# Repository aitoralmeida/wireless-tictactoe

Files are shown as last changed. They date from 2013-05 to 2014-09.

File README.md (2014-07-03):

wireless-tictactoe
==================

Wireless Tic-Tac-Toe for the THOFU project

Tested with Arduino Mega 2560

Uses https://github.com/joruiz/shiftduino to control the shift registers

 * TicTacToe folder contains the Arduino code
 * PCBSchemas folder contains the Eagle PCB schemas (Square folder contais the schema for each one of the 9 squares)

   This work has been supported by project grant CEN-20101019 (THOFU), funded
by the Spanish Centro para el Desarrollo Tecnol ogico Industrial (CDTI) and
supported by the Spanish Ministerio de Economía y Competitividad.

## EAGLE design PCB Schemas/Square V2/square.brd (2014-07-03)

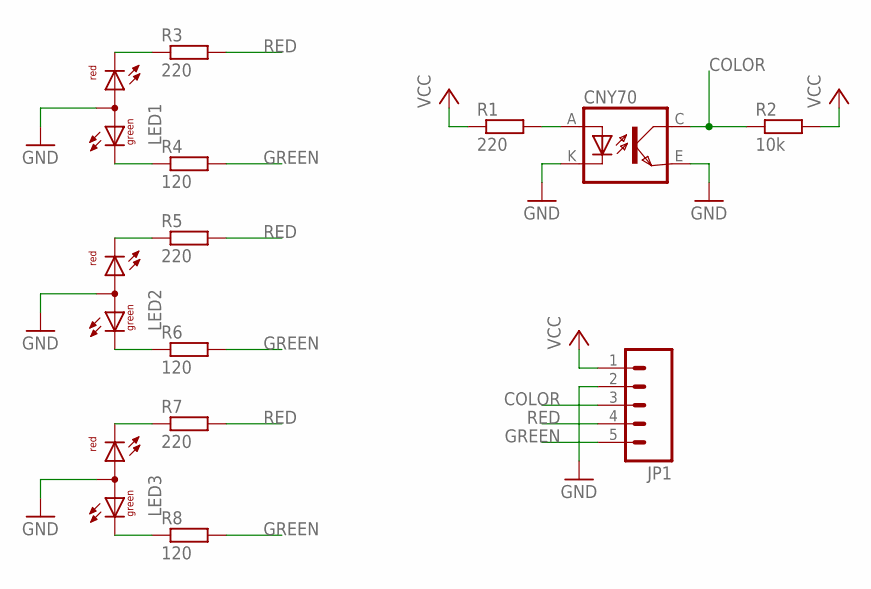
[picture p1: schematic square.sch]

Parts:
CNY70: CNY70; 4
JP1: M05PTH; 1X05
LED1, LED2, LED3: L-115WEGW-CA; DUOLED-A-3MM
R1, R3, R5, R7: 220; 0204/7
R2: 10k; 0204/7
R4, R6, R8: 120; 0204/7

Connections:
COLOR: CNY70.C (COL), JP1.3, R2.1
GND: CNY70.E (EMI), CNY70.K (C), JP1.2, LED1.2 (A), LED2.2 (A), LED3.2 (A)
GREEN: JP1.5, R4.2, R6.2, R8.2
unnamed: CNY70.A, R1.2
unnamed: LED1.3 (CR), R3.1
unnamed: LED2.3 (CR), R5.1
unnamed: LED3.3 (CR), R7.1
unnamed: LED2.1 (CG), R6.1
unnamed: LED1.1 (CG), R4.1
unnamed: LED3.1 (CG), R8.1
RED: JP1.4, R3.2, R5.2, R7.2
VCC: JP1.1, R1.1, R2.2

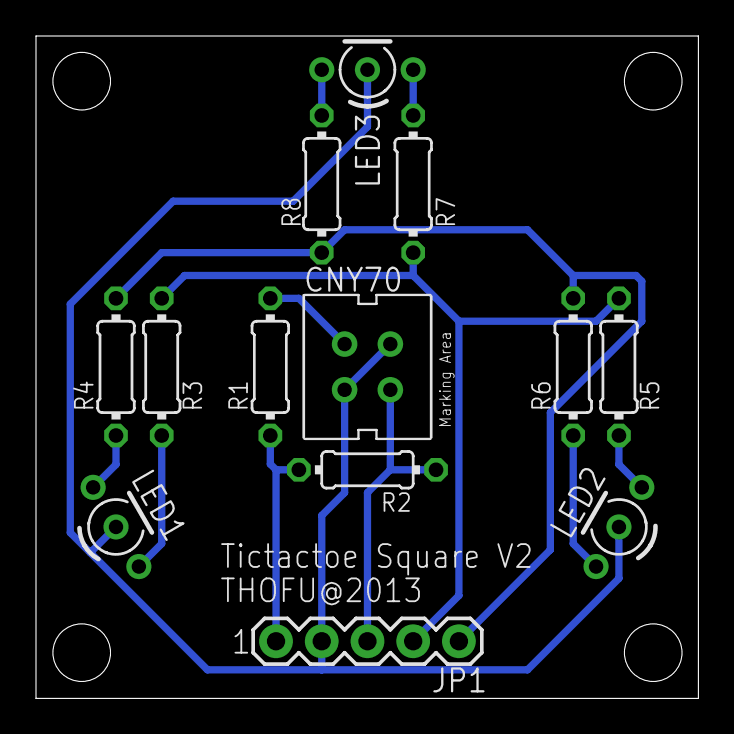
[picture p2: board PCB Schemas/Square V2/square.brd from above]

Board: 2 copper layers, 36.8 x 36.8 mm, 13 parts (0 on the bottom side), 12 nets.

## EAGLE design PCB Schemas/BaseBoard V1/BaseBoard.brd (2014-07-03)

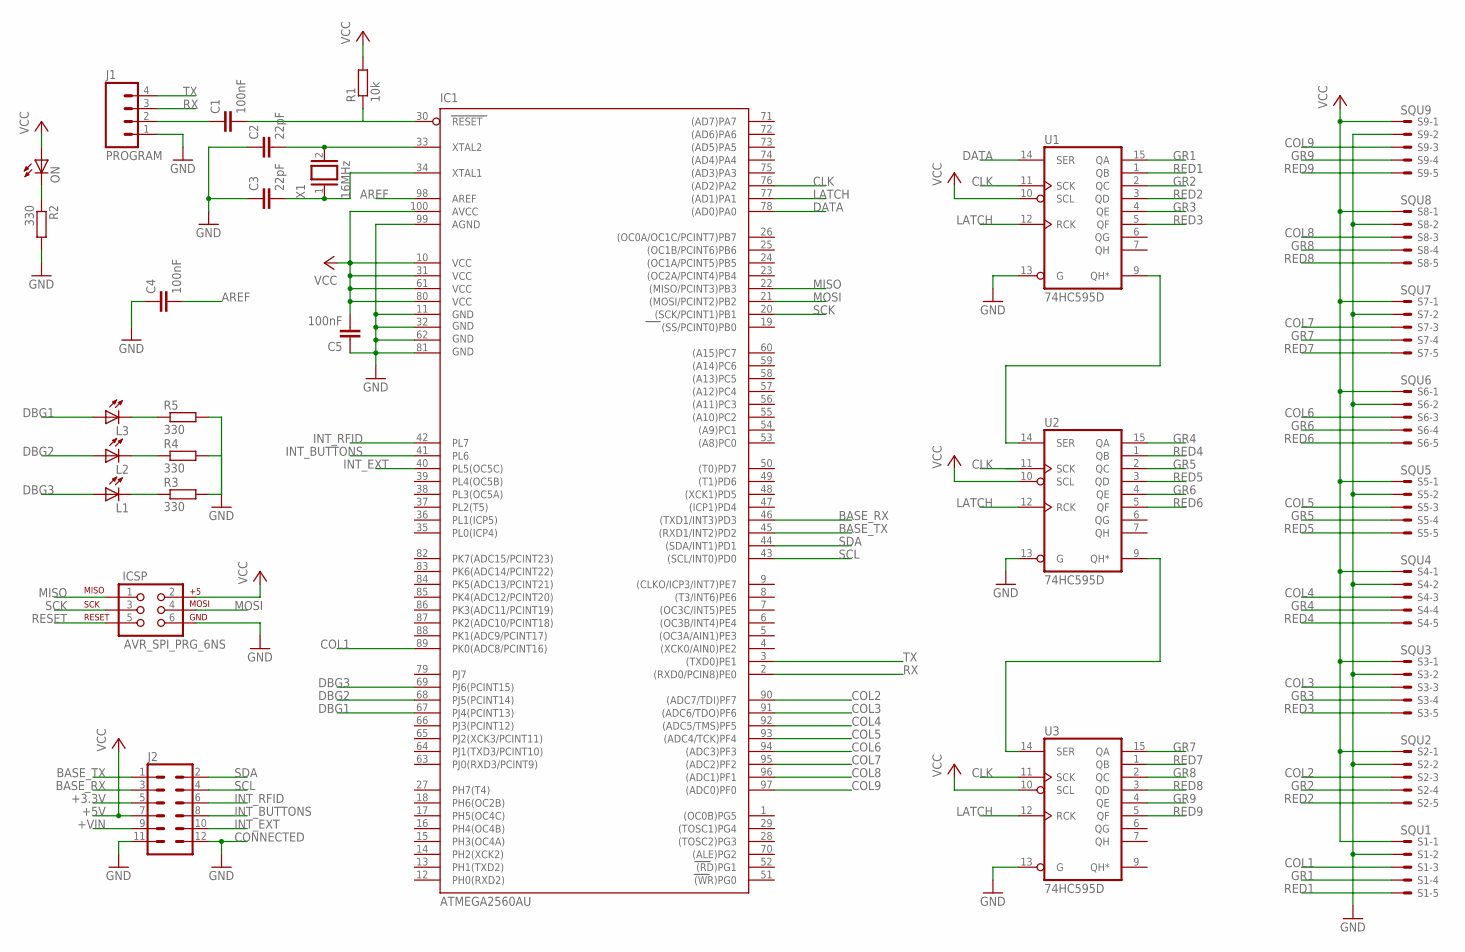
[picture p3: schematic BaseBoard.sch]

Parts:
C1, C4, C5: 100nF; C0805
C2, C3: 22pF; C0805
IC1: ATMEGA2560AU; TQFP100
ICSP: AVR_SPI_PRG_6NS; 2X3-NS
J1: PROGRAM; 1X04
J2: CON06X2-2MM; CON06X2_2MM
L1, L2, L3: LEDCHIP-LED0805; CHIP-LED0805
ON: LEDCHIP-LED0805; CHIP-LED0805
R1: 10k; R0805
R2, R3, R4, R5: 330; R0805
S1: SQU1; 53261-05
S2: SQU2; 53261-05
S3: SQU3; 53261-05
S4: SQU4; 53261-05
S5: SQU5; 53261-05
S6: SQU6; 53261-05
S7: SQU7; 53261-05
S8: SQU8; 53261-05
S9: SQU9; 53261-05
U1, U2, U3: 74HC595D; SO16
X1: 16MHz; QS

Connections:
+3.3V: J2.5
+VIN: J2.9
AREF: C4.2, IC1.98 (AREF)
BASE_RX: IC1.46 ((TXD1/INT3)PD3), J2.3
BASE_TX: IC1.45 ((RXD1/INT2)PD2), J2.1
CLK: IC1.76 ((AD2)PA2), U1.11 (SCK), U2.11 (SCK), U3.11 (SCK)
COL1: IC1.89 (PK0(ADC8/PCINT16)), S1.3
COL2: IC1.90 ((ADC7/TDI)PF7), S2.3
COL3: IC1.91 ((ADC6/TDO)PF6), S3.3
COL4: IC1.92 ((ADC5/TMS)PF5), S4.3
COL5: IC1.93 ((ADC4/TCK)PF4), S5.3
COL6: IC1.94 ((ADC3)PF3), S6.3
COL7: IC1.95 ((ADC2)PF2), S7.3
COL8: IC1.96 ((ADC1)PF1), S8.3
COL9: IC1.97 ((ADC0)PF0), S9.3
DATA: IC1.78 ((AD0)PA0), U1.14 (SER)
DBG1: IC1.67 (PJ4(PCINT13)), L3.A
DBG2: IC1.68 (PJ5(PCINT14)), L2.A
DBG3: IC1.69 (PJ6(PCINT15)), L1.A
GND: C2.1, C3.1, C4.1, C5.1, IC1.11 (GND), IC1.32 (GND1), IC1.62 (GND2), IC1.81 (GND3), IC1.99 (AGND), ICSP.6, J1.1, J2.11, J2.12, R2.2, R3.2, R4.2, R5.2, S1.2, S2.2, S3.2, S4.2, S5.2, S6.2, S7.2, S8.2, S9.2, U1.8 (GND), U1.13 (G), U2.8 (GND), U2.13 (G), U3.8 (GND), U3.13 (G)
GR1: S1.4, U1.15 (QA)
GR2: S2.4, U1.2 (QC)
GR3: S3.4, U1.4 (QE)
GR4: S4.4, U2.15 (QA)
GR5: S5.4, U2.2 (QC)
GR6: S6.4, U2.4 (QE)
GR7: S7.4, U3.15 (QA)
GR8: S8.4, U3.2 (QC)
GR9: S9.4, U3.4 (QE)
INT_BUTTONS: IC1.41 (PL6), J2.8
INT_EXT: IC1.40 (PL5(OC5C)), J2.10
INT_RFID: IC1.42 (PL7), J2.6
LATCH: IC1.77 ((AD1)PA1), U1.12 (RCK), U2.12 (RCK), U3.12 (RCK)
MISO: IC1.22 ((MISO/PCINT3)PB3), ICSP.1
MOSI: IC1.21 ((MOSI/PCINT2)PB2), ICSP.4
unnamed: C2.2, IC1.33 (XTAL2), X1.2
unnamed: C3.2, IC1.34 (XTAL1), X1.1
unnamed: L2.C, R4.1
unnamed: L1.C, R3.1
unnamed: C1.1, J1.2
unnamed: U1.9 (QH*), U2.14 (SER)
unnamed: U2.9 (QH*), U3.14 (SER)
unnamed: ON.C, R2.1
unnamed: L3.C, R5.1
RED1: S1.5, U1.1 (QB)
RED2: S2.5, U1.3 (QD)
RED3: S3.5, U1.5 (QF)
RED4: S4.5, U2.1 (QB)
RED5: S5.5, U2.3 (QD)
RED6: S6.5, U2.5 (QF)
RED7: S7.5, U3.1 (QB)
RED8: S8.5, U3.3 (QD)
RED9: S9.5, U3.5 (QF)
RESET: C1.2, IC1.30 (RESET), ICSP.5, R1.1
RX: IC1.2 ((RXD0/PCIN8)PE0), J1.3
SCK: IC1.20 ((SCK/PCINT1)PB1), ICSP.3
SCL: IC1.43 ((SCL/INT0)PD0), J2.4
SDA: IC1.44 ((SDA/INT1)PD1), J2.2
TX: IC1.3 ((TXD0)PE1), J1.4
VCC: C5.2, IC1.10 (VCC), IC1.31 (VCC1), IC1.61 (VCC2), IC1.80 (VCC3), IC1.100 (AVCC), ICSP.2, J2.7, ON.A, R1.2, S1.1, S2.1, S3.1, S4.1, S5.1, S6.1, S7.1, S8.1, S9.1, U1.10 (SCL), U1.16 (VCC), U2.10 (SCL), U2.16 (VCC), U3.10 (SCL), U3.16 (VCC)

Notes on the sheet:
CONNECTED
+5V

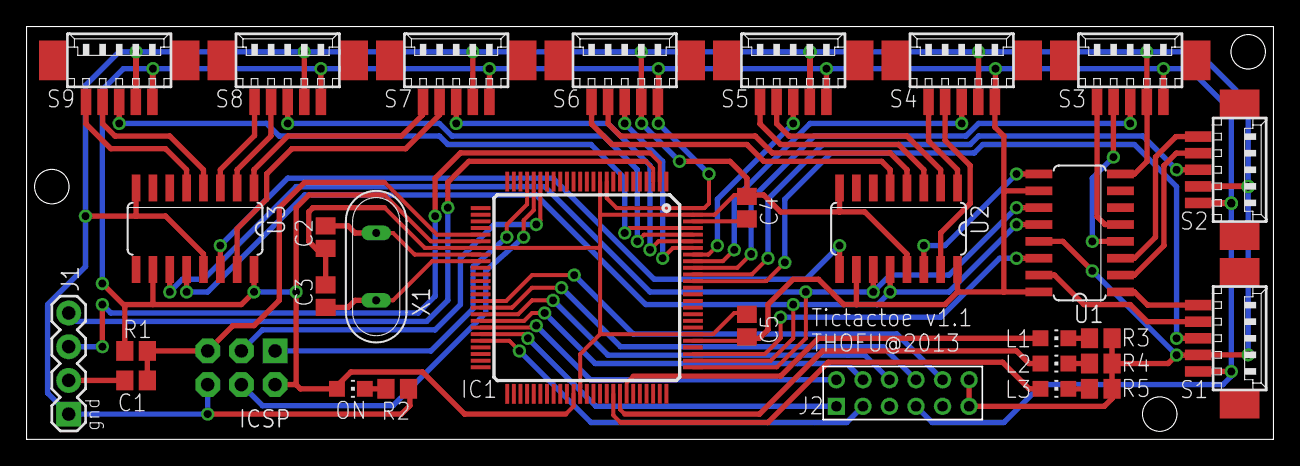
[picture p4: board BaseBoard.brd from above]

Board: 2 copper layers, 94.0 x 31.1 mm, 31 parts (0 on the bottom side), 58 nets.

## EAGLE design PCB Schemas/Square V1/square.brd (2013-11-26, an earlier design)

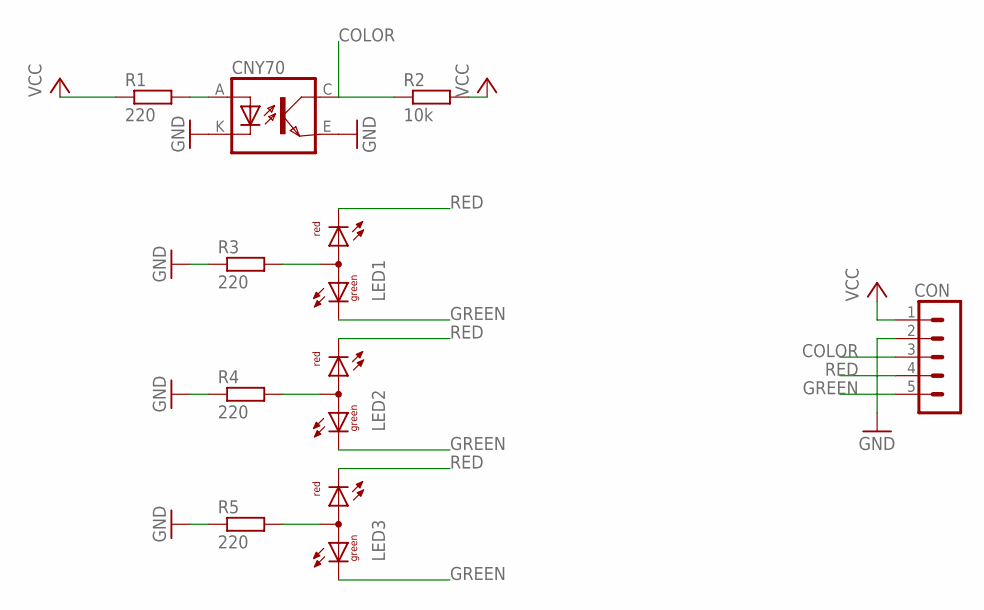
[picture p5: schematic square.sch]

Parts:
CNY70: CNY70; 4
CON: CON05; CON05_2.54MM
LED1, LED2, LED3: L-115WEGW-CA; DUOLED-A-3MM
R1, R3, R4, R5: 220; 0204/7
R2: 10k; 0204/7

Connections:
COLOR: CNY70.C (COL), CON.3, R2.1
GND: CNY70.E (EMI), CNY70.K (C), CON.2, R3.1, R4.1, R5.1
GREEN: CON.5, LED1.1 (CG), LED2.1 (CG), LED3.1 (CG)
unnamed: LED1.2 (A), R3.2
unnamed: CNY70.A, R1.2
unnamed: LED2.2 (A), R4.2
unnamed: LED3.2 (A), R5.2
RED: CON.4, LED1.3 (CR), LED2.3 (CR), LED3.3 (CR)
VCC: CON.1, R1.1, R2.2

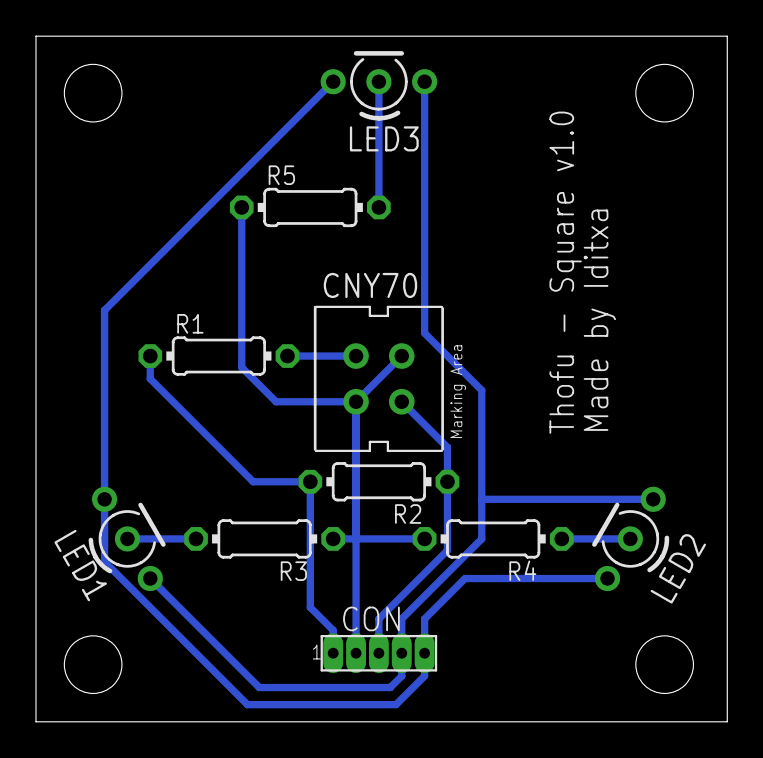
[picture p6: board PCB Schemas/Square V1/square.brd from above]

Board: 2 copper layers, 38.4 x 38.1 mm, 10 parts (0 on the bottom side), 9 nets.

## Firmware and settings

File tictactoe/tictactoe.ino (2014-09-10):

#include <Shiftduino.h>
#include "Square.h"

#include <Wire.h>
#include <GraphicDisplay.h>
#include <SM125.h> //RFID
#include <SoundPlayer.h>

//Game ID
#define GAME_ID 0x01 //tictactoe
//Board ID
#define BOARD_ID 0x07 //TODO: Change it for each board
#define PLAYER__ID "7000"

// Hardware addresses
#define DISPLAY_ADDRESS  0x51
#define BUTTONS_CHANGE   43
#define SM125_ADDRESS 0x46
// Sound files
#define WELCOME 0x1 //Welcome screen
#define YOU_WIN 0x2 //The Player wins :-)
#define YOU_LOSE 0x3 //The Rival wins :-(
#define VICTORY_LOOP 0x4 //Victory loop!!!
#define NO_NO 0x7 //Illegal move
// Image addresses
#define GAME_OVER 0x0049
#define WINNER 0x00DB
#define TICTACTOE 0x0092
#define DOWN_OFFSET 11 // How many pixels we are leaving for the status bar

// Communication msgs
String MSG_REGISTER = "REGISTER"; // id
String MSG_FIND_GAME = "FIND_GAME"; // id
String MSG_DO_MOVE =  "DO_MOVE"; // id movement(0..8)
String MSG_GET_MOVE = "GET_MOVE"; // id
String MSG_GAMEID = "GAMEID"; //id
String MSG_OK = "OK";
String END_CHAR = "\r"; 
String SEP_CHAR_COMMANDS = " ";
String SEP_CHAR_PARAMETERS = ",";
// Server commands
String CMD_WAITING_PLAYERS = "WAITING_FOR_PLAYERS";
String CMD_RIVAL = "RIVAL"; // rival_id turn(0/1)
String CMD_NOT_REGISTERED = "NOT_REGISTERED";
String CMD_WAIT_FOR_MOVE = "WAIT_FOR_MOVE";
String CMD_WAIT_FOR_RIVAL = "WAIT_FOR_RIVAL";
String CMD_WAIT_FOR_TURN = "WAIT_FOR_TURN";
String CMD_RIVAL_MOVE = "RIVAL_MOVE"; // # rival_id move
String CMD_ACK = "ACK"; // rival_id move
String CMD_START_PLAYING = "PLAY";
String CMD_GET_GAMEID = "GET_GAMEID";



// Baseboard screen
GraphicDisplay display;
// Baseboard RFID reader
SM125 sm125;
// Baseboard sound player
SoundPlayer soundPlayer;

// Configuration for the shift registers
int numShifts = 3;
int datapin = 22;
int clockpin = 24;
int latchpin = 23;

Shiftduino _sd(datapin, clockpin, latchpin, numShifts);

// Unique board ID (TODO: right now is set manually for testing purposes)
String player_id = PLAYER__ID;
// Rival board id
String rival_id = "0";
// Who starts playing: 0 the player, 1 the rival.
String start_turn = "2";

// Current turn
int turn = 0;

// Each of the squares of the tictactoe
Square * squares[9];

//int gameStatus = 0; //0 = ongoing game, 1 = you win, 2 = opponent wins
//int currentTurn = 0; //0 you, 1 opponent

// square status
int redStatus [] = {
  0,0,0,0,0,0,0,0,0};
int greenStatus [] = {
  0,0,0,0,0,0,0,0,0};
int previousGreenStatus [] = {
  0,0,0,0,0,0,0,0,0};

// conditions for victory
int winConditions [][9] = {
  {
    1,1,1,0,0,0,0,0,0  }
  ,
  {
    0,0,0,1,1,1,0,0,0  }
  ,
  {
    0,0,0,0,0,0,1,1,1  }
  ,
  {
    1,0,0,1,0,0,1,0,0  }
  ,
  {
    0,1,0,0,1,0,0,1,0  }
  ,
  {
    0,0,1,0,0,1,0,0,1  }
  ,
  {
    1,0,0,0,1,0,0,0,1  }
  ,
  {
    0,0,1,0,1,0,1,0,0  }
};

boolean redVictory = false;
boolean greenVictory = false;

// hardware initialization
void setup() {
  // 0 - Initialize serial comms  
  Serial.begin(9600); // USB comm for debugging purposes
  Serial1.begin(9600); // Comm with the base board
  
  Serial.println("*****************");
  Serial.println("***** Setup *****");
  Serial.println("*****************");
  
  // 1 - Initialize the tictactoe board
  Serial.println("Initializing tictactoe squares...");
  
  for (int i = 0; i < 9; i++){
    squares[i] = new Square(8 - i, i + 1, &_sd);
  }
  Serial.println("-Calibrating sensors.");
  calibrateSensors();
  
  Serial.println("-Testing squares.");
  delay(100);
  clearSquares();
  Serial.println("--Green.");
  allGreen();
  delay(500);
  clearSquares();
  Serial.println("--Red.");
  allRed();
  delay(500);
  clearSquares();
  delay(100);
  
  Serial.println("-Squares initialized.");
  Serial.println("");
  // 2 - Initialize the baseboard peripherals 
  initializeHardwarePeripherals();
  Serial.println("");
  // 3 - Show the welcome message
  doWelcome();
  Serial.println("");  
  // 4 - Register the player in the server
  registerPlayer();
  Serial.println("");
  // 5 - Find other player
  display.clear();
  display.printText("Waiting for players...", 6, 1, GREEN);
  findPlayer();
  Serial.println("");
}

void loop() {
  Serial.println("*********************");
  Serial.println("***** Game Loop *****");
  Serial.println("*********************");
  Serial.println("-Turn: " + String(turn));
  Serial.println("-Start turn: " + start_turn);
  Serial.println("");
  delay(200);
  boolean waitForMove = true;

  if ((turn > 0) || (turn == 0 && start_turn.startsWith("YES"))){
    // ************************************************************************
    // ******** Player turn ***************************************************
    // ************************************************************************
    Serial.println("***** Player turn *****");
    for (int i = 0; i < 9; i++){
      previousGreenStatus[i] = greenStatus[i];
    }
    // 1 -Update color status
    //   -Check player move, wait until it happens
    printMsg("Your turn.");

    int player_move = 0;
    
    Serial.println("Waiting for move...");
    while (waitForMove){
      updateBoardStatus();  
      player_move = checkPlayerMove();
      if (player_move == -1){
        // No move, wait and check again
        delay(30);
      }
      else if (player_move > -1){
        // Legal move, continue
        waitForMove = false;
        Serial.println("Legal move: " + String(player_move));
      } 
      else if (player_move == -2){
        // Player has moved 2 pieces, illegal move      
        msgAndWait("You moved two pieces!");
        Serial.println("Illegal Move: Moved two pieces.");
        soundPlayer.play(NO_NO);      
      } 
      else if (player_move == -3){
        // Player has moved the piece into an square already used.     
        msgAndWait("You moved your piece into an already used square!");
        Serial.println("Illegal move: moved into an already used square.");
        soundPlayer.play(NO_NO);  
      }
    }

    // 2- Send move to server  
    sendMove(player_move);

    // 3 -Check victory conditions
    Serial.println("Check win conditions.");
    greenVictory = checkWin(greenStatus);
    if (greenVictory){
      Serial.println("The Player wins.");
      //printMsg("A winner is you");
      display.drawImage(0x0000, WINNER, 0, DOWN_OFFSET); 
      soundPlayer.play(YOU_WIN);
      victoryLoop('g');
    } else{
      turn = turn + 1;
    }
  }

  if ((turn > 0) || (turn == 0 && start_turn.startsWith("NO"))){
    // ************************************************************************
    // ******* Rival turn *****************************************************
    // ************************************************************************
    Serial.println("***** Rival turn *****");
    printMsg("Wait for your rival's move.");

    // 1- Check rival move, wait until it happens
    Serial.println("Getting Rival's move...");
    Serial.println("");
    int rival_move = -1;
    rival_move = getMove();

    // 2- Update color status
    Serial.println("Updating color status...");
    if (rival_move > -1 && rival_move  < 9){
      redStatus[rival_move] = 1;
      squares[rival_move]->setRed();
    }

    // 3 -Check victory conditions
    Serial.println("Checking win contitions...");
    redVictory = checkWin(redStatus);
    if (redVictory){
      Serial.println("The Rival wins.");
      //printMsg("You lose!");
      display.drawImage(0x0000, GAME_OVER, 0, DOWN_OFFSET); 
      soundPlayer.play(YOU_LOSE); 
      victoryLoop('r');
    } else{
      turn = turn + 1;
    }
  }
}

/**********************************************
 *   BASEBOARD HARDWARE INITIALIZATION
 **********************************************/

void initializeHardwarePeripherals(){
  Serial.println("Initializing hardware:");
  initializeBoard();
  initializeScreen();
  display.printText("Initializing...", 6, 1, GREEN);
  initializeRFID();
  initializeSoundPlayer();  
  Serial.println("Hardware initialized");
}

void initializeBoard(){
  Serial.println("-Initializing board...");
  boolean waitToBoard = true;
  String msg = "";
  Serial.println("--Waiting for board reply...");
  while (waitToBoard){
    delay(100);
    while (Serial1.available()){
      char data = Serial1.read();
      msg += data;   
    }

    int index = msg.indexOf(END_CHAR);
    if (index != -1){
      Serial.println("--Received: " + msg);
      String command = getCommand(msg);
      Serial.println("Command: '" + command + "'");
      if (command.startsWith(CMD_GET_GAMEID)){  
        String reply = MSG_GAMEID + SEP_CHAR_COMMANDS + String(GAME_ID) + END_CHAR;
        Serial.println("--Sending: '" + reply + "'");
        Serial1.print(reply);
      }
      else if (command.startsWith(CMD_START_PLAYING)){
        String reply = MSG_OK + END_CHAR;
        Serial.println("--Sending: " + reply);
        Serial1.print(reply);
        waitToBoard = false;
      } 
      msg = "";  
    }
  }
}

void initializeRFID(){
  Serial.println("-Initializing RFID...");
  sm125.begin(SM125_ADDRESS);
}

void initializeSoundPlayer(){
  Serial.println("-Initializing sound player...");
  soundPlayer.begin(0x61);
  int ver = soundPlayer.getVersion();  
  switch(ver)
  {
  case 0x10:
    Serial.println("--Version: 1.0");
    break;
  }
}

void initializeScreen(){
  Serial.println("-Initializing screen...");
  pinMode(BUTTONS_CHANGE, INPUT);
  display.begin(DISPLAY_ADDRESS, BUTTONS_CHANGE);
  //wait for display initialization
  do {
    delay(50);
  }
  while(!display.isReady());
  //get firmware version
  int ver = display.getVersion();
  switch(ver)
  {
  case 0x10:
    Serial.println("--Version 1.0");
    break;
  }

  display.clear();
}

/**********************************************
 *   SCREEN PRONTS
 **********************************************/



void doWelcome(){
  Serial.println("***** doWelcome *****");
  display.clear();
  soundPlayer.stop();
  //display.printText("Welcome to the tictactoe game!", 6, 1, BLUE);
  display.drawImage(0x0000, TICTACTOE, 0, DOWN_OFFSET);
  soundPlayer.play(WELCOME);
  delay(1000);
  display.clear();
  display.printText("Press the green button to find another player...", 6, 1, GREEN);
  boolean doLoop = true;
  while(doLoop){
    if (display.buttonsChanged()) {
      byte reply = display.getButtons();
      // Green button
      if ((reply & 0x04) == 0x00){
        doLoop = false;
        soundPlayer.stop();
      }
    }  
  }
  display.clear();
  display.printText("Starting a new game!", 6, 1, GREEN);
  Serial.println("Starting new game");
  delay(300); 

}

void msgAndWait(String msg){
  display.clear();
  display.printText(msg, 6, 1, RED);
  boolean doLoop = true;
  while(doLoop){
    if (display.buttonsChanged()) {
      byte reply = display.getButtons();
      // Green button
      if ((reply & 0x04) == 0x00){
        doLoop = false;
      }
    }  
  }
  display.clear(); 
}

void printMsg(String msg){
  display.clear();
  display.printText(msg, 6, 1, BLUE);
}

/**********************************************
 *   COMMUNICATION WITH THE GAME SERVER
 **********************************************/

void registerPlayer(){
  Serial.println("Registering player...");
  sendMsg(MSG_REGISTER + SEP_CHAR_COMMANDS + player_id + END_CHAR);
}

void findPlayer(){
  Serial.println("Finding other player...");
  boolean notFound = true;
  while(notFound){
    Serial.println("-Searching for other players...");
    String res = sendAndWait(MSG_FIND_GAME + SEP_CHAR_COMMANDS  + player_id + END_CHAR);
    Serial.println("-reply: '" + res + "'");
    String command = getCommand(res);

    // if waiting_for_player -> delay 100
    // if not_registered -> register
    // if rival -> set start_turn, set rival_id, notFound = false
    if (command.startsWith(CMD_WAITING_PLAYERS)){
      Serial.println("-Waiting for rivals...");
      delay(1000);
    } 
    else if (command.startsWith(CMD_NOT_REGISTERED)){ // This shouldn't happen
      Serial.println("-Not registered");
      registerPlayer();
    } 
    else if (command.startsWith(CMD_RIVAL)){
      Serial.println("-Rival found");
      String parameters = getParameters(res);
      rival_id = getParameter(parameters, 1);
      start_turn = getParameter(parameters, 2);
      notFound = false;
    } else{
      Serial.println("Unknown command: '" + command + "'");
    
    }
  }
}

int getMove(){
  Serial.println("Getting rival's move...");
  boolean notMove = true;
  int rivalMove = -1;

  while(notMove){
    String res = sendAndWait(MSG_GET_MOVE + SEP_CHAR_COMMANDS + player_id + END_CHAR);
    String command = getCommand(res);

    //if wait_for_move -> delay 1000
    //if rival_move -> notFound = false, rival_move = res 2
    if (command.startsWith(CMD_WAIT_FOR_MOVE)){
      Serial.println("Waiting for rival's move...");
      delay(1000);
    } 
    else if (command.startsWith(CMD_RIVAL_MOVE)){
      String parameters = getParameters(res);
      String strMove = getParameter(parameters, 2);      
      rivalMove = strMove.toInt();
      notMove = false;
    }    
  }

  return rivalMove;
}

void sendMove(int player_move){
  Serial.println("Sending move...");
  boolean notReceived = true;

  //If ack -> notReceived = false
  //If wait_for_rival -> delay 1000
  String res = sendAndWait(MSG_DO_MOVE + SEP_CHAR_COMMANDS + player_id + SEP_CHAR_PARAMETERS  + player_move +  END_CHAR);
  Serial.println("Reply: '" + res + "'");
  String command = getCommand(res);
  while(notReceived){    
    if (command.startsWith(CMD_ACK)){
      Serial.println("Sent");
      notReceived = false;
    } 
    else if (command.startsWith(CMD_WAIT_FOR_RIVAL) || command.startsWith(CMD_WAIT_FOR_TURN)){
      Serial.println("Waiting for the rival to retrieve previous move...");
      delay(1000);
      res = sendAndWait(MSG_DO_MOVE + SEP_CHAR_COMMANDS + player_id + SEP_CHAR_PARAMETERS  + player_move +  END_CHAR);
      Serial.println("Reply: '" + res + "'");
      command = getCommand(res);
    } else {
      Serial.println("Unknown command: '" + command + "'");
      delay(1000);
      res = sendAndWait(MSG_DO_MOVE + SEP_CHAR_COMMANDS + player_id + SEP_CHAR_PARAMETERS  + player_move +  END_CHAR);
      Serial.println("Reply: '" + res + "'");
      command = getCommand(res);
    } 
  }
}

void sendMsg(String msg){
  Serial1.print(msg);
}

String sendAndWait(String msg){ 
  Serial1.print(msg);

  // Wait for the reply
  String res = "";
  while (true){
    if (Serial1.available()){
      char data = Serial1.read();
      res += data;   
      if (data == '\r'){
        break;
      }
    }
  }

  return res; 
}


/**********************************************
 *   CNY70 SENSOR CALIBRATION
 **********************************************/

// The calibration changes from sensor to sensor
// The values are unique for each board and sensor

// New painted pieces
void calibrateSensors(){
  // int maxGreen, int minGreen, int maxRed, int minRed
  for(int i = 0; i < 9; i++){
    squares[i]->calibrateCNY70(450, 0, 830, 460);
    delay(10);
  }
}

/*
// Old pieces with the colors that the 3D printer uses
void calibrateSensors(){
  // int maxGreen, int minGreen, int maxRed, int minRed
  squares[0]->calibrateCNY70(310, 270, 350, 320);
  squares[1]->calibrateCNY70(440, 415, 480, 460);
  squares[2]->calibrateCNY70(280, 220, 335, 310);
  squares[3]->calibrateCNY70(325, 250, 375, 340);
  squares[4]->calibrateCNY70(420, 380, 460, 435);
  squares[5]->calibrateCNY70(200, 140, 250, 205);
  squares[6]->calibrateCNY70(320, 280, 370, 330);
  squares[7]->calibrateCNY70(240, 190, 310, 250);
  squares[8]->calibrateCNY70(220, 170, 270, 245);  
}
*/


/**********************************************
 *   GAME LOGIC
 **********************************************/

// -1 -> no move
// -2 -> illegal move, 2 pieces moved
// -3 -> illegal move, moved into a square used by the rival
// 0..8 -> legal move
int checkPlayerMove(){
  int totalMoves = 0;
  int player_move = 0;
  char color;
  for(int i = 0; i < 9; i++){
    color = squares[i]->checkColor();
    if (previousGreenStatus[i] != greenStatus[i]){
      totalMoves++;
      player_move = i;
    }
  }

  if (totalMoves == 0) {
    // The player has not done any move
    player_move = -1;
  } 
  else if (totalMoves > 1) {
    // The player has moved 2 pieces, which is an illegal move
    player_move = -2;
  }
  else if (color == 'r'){
    // The player has moved his piece into an square already used by the rival
    player_move = -3;
  }

  return player_move;  
}

void updateBoardStatus(){
  for (int i=0; i < 9; i++){
    char color = squares[i]->checkColor();
    if (color == 'g'){
      squares[i]->setGreen();
      greenStatus[i] = 1;
    }
  }
}

void updateColorStatus(){
  for (int i=0; i < 9; i++){
    char color = squares[i]->checkColor();
    if (color == 'g'){
      squares[i]->setGreen();
      greenStatus[i] = 1;
    } 
    else if (color == 'r'){
      squares[i]->setRed();
      redStatus[i] = 1;
    } 
    else{
      squares[i]->clear();
      redStatus[i] = 0;
      greenStatus[i] = 0;
    }
  }  
}

boolean isSame(int array1[], int array2[]){
  boolean same = true;
  
  for (int i=0; i < 9; i++){
    if (same==false){
      break;
    }
    if (array1[i] == array2[i]){
      same = true;
    } 
    else {
      same = false;
    }
  }
  return same;
} 


boolean checkWin(int statusArray[]){
  printStatus("Green Status", greenStatus);
  printStatus("Status array", statusArray);
  boolean win = false;
  for (int i=0; i < 8; i++){
    if (win){
      break;
    }
    //Mask to only take the needed values
    int result[] = {
      0,0,0,0,0,0,0,0,0    };
    for (int j=0; j < 9; j++){
      result[j] = statusArray[j] * winConditions[i][j];
    }  
    printStatus("Result", result);
    printStatus("WinStatus", winConditions[i]);
    win = isSame(result, winConditions[i]); 
  }
  return win;  
}

void checkColor(int s){
  int colorValue = squares[s]->getColorValue();
  Serial.println(colorValue);
}

void victoryLoop(char color){
  boolean doVictory = true;
  soundPlayer.play(VICTORY_LOOP);
  while (doVictory){
    for (int i=0; i < 9; i++){
      clearSquares();
      if (color == 'g'){
        squares[i]->setGreen();
      } 
      else if (color == 'r'){
        squares[i]->setRed();
      } 
      delay(100);
    }

    if (color == 'g'){
      allGreen();
    } 
    else if (color == 'r'){
      allRed();
    } 
    delay(100);

    /*
    printMsg("Press green button for another game");
    if (display.buttonsChanged()) {
      byte reply = display.getButtons();
      // Green button
      if ((reply & 0x04) == 0x00){
        doVictory = false;
        soundPlayer.stop();
        // new game!
        restartGame(); 
      }
    }
    */
  }
}


void restartGame(){

  clearSquares();
  allGreen();
  delay(200);
  allRed();
  delay(200);
  allGreen();
  delay(600);
  clearSquares();

  // initialize rival id
  rival_id = 0;

  // initialize status
  for (int i=0; i < 9; i++){
    redStatus[i] = 0;
    greenStatus[i] = 0;
    previousGreenStatus[i] = 0;
  } 

  // initialize squares
  for (int i = 0; i < 9; i++){
    squares[i] = new Square(8 - i, i + 1, &_sd);
  }

  // initialize victory
  redVictory = false;
  greenVictory = false;

  // Show the welcome message
  doWelcome();  

  // Find other player
  findPlayer();
}

void printStatus(String name, int statusArray[]){
  Serial.print(name + ": ");
  for (int i = 0; i < 9; i++){
    Serial.print(String(statusArray[i]));
  }
  Serial.println();
}


/**********************************************
 *   COLOR CONTROL METHODS
 **********************************************/

void clearSquares(){
  for (int i=0; i < 9; i++){
    squares[i]->clear();
  }
}

void allRed(){
  for (int i=0; i < 9; i++){
    squares[i]->setRed();
  }
}

void allGreen(){
  for (int i=0; i < 9; i++){
    squares[i]->setGreen();
  }
}


void printStatus(){
  Serial.println("Red");
  for (int i=0; i < 9; i++){
    Serial.println(redStatus[i]);
  }
  Serial.println();

  Serial.println("Green");
  for (int i=0; i < 9; i++){
    Serial.println(greenStatus[i]);
  }
  Serial.println();
}

/**********************************************
 *   COMMUNICATION METHODS
 **********************************************/

// getCommand
//
// Get the command string of the message
String getCommand(String message) {

  int index = message.indexOf(' ');
  if (index != -1)
    return message.substring(0, index);
  else
    return message;
}

// getParameters
//
// Get the parameters of the message
String getParameters(String message) {

  int index = message.indexOf(' ');
  if (index != -1)
    return message.substring(index + 1);
  else
    return "";
}

// numberOfParameters
//
// Get tne number of parameters
int numberOfParameters(String parameters) {

  if (parameters.equals(""))
    return 0;
  else {
    String temp = parameters;
    int count = 0, index;
    do {
      index = temp.indexOf(',');
      temp = temp.substring(index + 1);
      count++;
    }
    while (index >= 0);
    return count;
  }
}

// getParamenter
//
// Get a parameter defined for its position (1, 2, 3...)
String getParameter(String parameters, int position) {

  String temp = parameters, parameter;
  int count = 0, index;
  do {
    index = temp.indexOf(',');
    parameter = temp.substring(0, index);
    temp = temp.substring(index + 1);
    count++;
  }
  while (count != position);
  return parameter;
}

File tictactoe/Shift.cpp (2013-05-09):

/*
  Library to control the 74HC595
  More info at http://bildr.org/?s=74hc595
*/

#include "Arduino.h"
#include "Shift.h"

int SER_Pin = 8;   //pin 14 on the 75HC595
int RCLK_Pin = 9;  //pin 12 on the 75HC595
int SRCLK_Pin = 10; //pin 11 on the 75HC595

//How many of the shift registers - change this
#define number_of_74hc595s 1 

//do not touch
#define numOfRegisterPins number_of_74hc595s * 8

boolean registers[numOfRegisterPins];

void initialize(){
  pinMode(SER_Pin, OUTPUT);
  pinMode(RCLK_Pin, OUTPUT);
  pinMode(SRCLK_Pin, OUTPUT);


  //reset all register pins
  clearRegisters();
  writeRegisters();
}               


//set all register pins to LOW
void clearRegisters(){
  for(int i = numOfRegisterPins - 1; i >=  0; i--){
     registers[i] = LOW;
  }
} 


//Set and display registers
//Only call AFTER all values are set how you would like (slow otherwise)
void writeRegisters(){

  digitalWrite(RCLK_Pin, LOW);

  for(int i = numOfRegisterPins - 1; i >=  0; i--){
    digitalWrite(SRCLK_Pin, LOW);

    int val = registers[i];

    digitalWrite(SER_Pin, val);
    digitalWrite(SRCLK_Pin, HIGH);

  }
  digitalWrite(RCLK_Pin, HIGH);

}

//set an individual pin HIGH or LOW
void setRegisterPin(int index, int value){
  registers[index] = value;
}


void loop(){

  setRegisterPin(2, HIGH);
  setRegisterPin(3, HIGH);
  setRegisterPin(4, LOW);
  setRegisterPin(5, HIGH);
  setRegisterPin(7, HIGH);


  writeRegisters();  //MUST BE CALLED TO DISPLAY CHANGES
  //Only call once after the values are set how you need.
}

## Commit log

2013-05-09 tests for the bi-color leds and the CNY70
2013-05-10 now controling 3 leds with 2 chainned shif registers
2013-05-16 reorganized the project
    [square.brd, square.sch]
2013-05-24 Updated and Finalized Square Board V1
    [square.brd, square.sch]
2013-05-30 Revised square board V1 and added components file
    [Componentes.xlsx, square.brd, square.sch]
2013-09-19 completed the schema, still need to add the comm bus
    [BaseBoard.brd, BaseBoard.sch]
2013-09-19 board still needs some work
    [BaseBoard.brd, BaseBoard.sch]
2013-09-20 changed schema and board
    [BaseBoard.brd, BaseBoard.sch]
2013-09-26 added first code to check the status of the board
2013-09-30 Square Version 1 finalized
    [square.GBL, square.GBO, square.GBP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]
2013-10-24 Finalized base board and square v2
    [BaseBoard.GBL, BaseBoard.GBO, BaseBoard.GBP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]
2013-11-13 Corrected BaseBoard V1 and updated license file
    [BaseBoard.brd, BaseBoard.sch]
2013-11-16 Modified base conector; delete reset pin
    [BaseBoard.brd, BaseBoard.sch]
2013-11-17 Update base conector package
    [BaseBoard.brd, BaseBoard.sch]
2013-11-22 Updated details
    [BaseBoard.brd, BaseBoard.sch, square.brd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]
2013-11-22 Changed debug pins
    [BaseBoard.brd, BaseBoard.sch]
2013-11-22 Revert "Changed debug pins"
    This reverts commit 73787cc4df0c0002b7e389e6993c433356a097db.
    [BaseBoard.brd, BaseBoard.sch]
2013-11-22 Added debug led test program and new pins_arduino.h directive file
2013-11-26 added test for all the leds and the cny70s
2013-12-05 Finalized V2 of base board
    [BaseBoard.GBL, BaseBoard.GBO, BaseBoard.GBP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]
2013-12-13 fixed bug calculating the led pins
2013-12-13 Implemented calibration and color adjust
2014-01-08 added checkColor method for calibration purposes
2014-06-06 Revised PCB schemas
    [BaseBoard.GBL, BaseBoard.GBO, BaseBoard.GBP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]
2014-07-04 fixed minor bug in isSame()
    [tictactoe.ino]
2014-07-15 changed the protocol in the arduino side also
2014-07-22 added the board initialization commands, still needs work
2014-07-22 added board initialization and communication methods
2014-07-22 added more logging msgs. Fixed bug when identifiying the commands.
    [tictactoe.ino]
2014-07-22 fixed turn identification bug
    [tictactoe.ino]
2014-07-22 new sensor calibration
2014-07-22 fixed bug in sendMove()
    [tictactoe.ino]
2014-07-22 fixed bug sending move
    [tictactoe.ino]
2014-07-23 fixed bug in sendAndWait()
    [tictactoe.ino]
2014-07-23 fixed the bug introduced in initializeBoard in the previous commit
    [tictactoe.ino]
2014-07-23 fixed getMove bug in server
    [tictactoe.ino]
2014-07-24 fixed bug in isSame()
    [tictactoe.ino]
2014-07-24 Moved some msgs and command to consts. The previous version works correctly
    [tictactoe.ino]
2014-09-08 new color calibration

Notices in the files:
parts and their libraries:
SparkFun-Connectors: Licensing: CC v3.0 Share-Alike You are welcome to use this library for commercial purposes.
